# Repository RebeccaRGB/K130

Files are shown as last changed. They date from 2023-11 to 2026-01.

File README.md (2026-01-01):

# K130
Battlestation keyboard with 130 keys! It's an ANSI keyboard! It's an ISO keyboard! It's a JIS keyboard! It's all of the above!

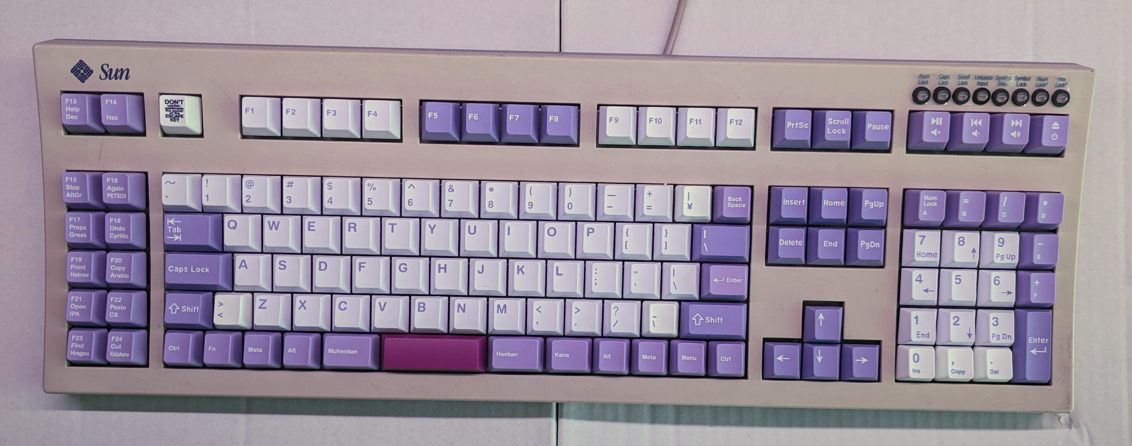
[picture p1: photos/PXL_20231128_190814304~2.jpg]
Thing 1


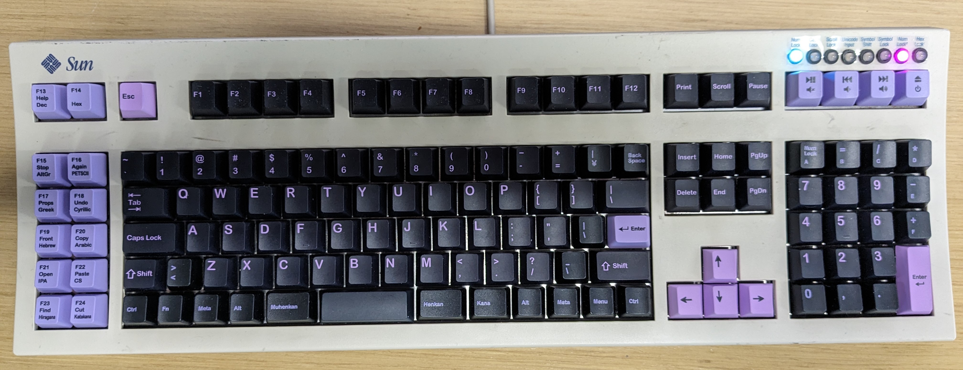
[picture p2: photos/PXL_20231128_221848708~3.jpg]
Thing 2


I have successfully built and used two of these keyboards, so the design and software is pretty much done, but the documentation is still a work in progress.

## Stuff to Get
* 130x Cherry MX compatible keyswitches
* 130x through-hole 1N4148 diodes
* 1x through-hole 1-pin male header
* 3x through-hole 4-pin 2.54mm-spacing male header
* 3x through-hole 5-pin 2.54mm-spacing male header
* 1x through-hole 11-pin 2.54mm-spacing male header
* 1x through-hole 12-pin 2.54mm-spacing male header
* 2x through-hole 14-pin 2.54mm-spacing male header
* 10x Mill-Max Manufacturing Corp 0906-8-15-20-76-14-11-0 POGO pins (FANCY!)
* 1x Teensy 4.0 microcontroller
* 1x through-hole 6-switch DIP switches
* 3x through-hole 150 ohm resistors
* 3x through-hole LEDs *or* 3x through-hole NeoPixel LEDs *or* 1x NeoPixel strip
* 1x USB-B connector *or* 1x microUSB-B connector
* 2x 2u stabilizers
* a standard set of keycaps
* a case specifically from a Sun Microsystems Type 5c keyboard (these are plentiful on eBay and you don't have to feel bad about gutting one since the membrane on these things is pure crap)

## Stuff to Make
* 1x keyboard matrix PCB, made from the Gerber files in the `K130-matrix-gerber` directory
* 1x keyboard encoder PCB, made from the Gerber files in the `K130-encoder-gerber` directory
* 1x aluminum mounting plate, made from the `K130-plate.svg` file
* a bunch of additional keycaps for the 30 or so other keys, made from the templates in the `keycaps` directory (more details needed)

## Stuff to Do
* Program the Teensy 4.0 microcontroller with the Arduino sketch in the `Arduino/K130` directory
* Solder in the diodes on the matrix PCB **first**
* Insert the stabilizers into the aluminum mounting plate
* Insert the keyswitches into the aluminum mounting plate and matrix PCB
* Double check with a multimeter that all the keyswitches work!
* Only **after** checking the keyswitches solder them to the matrix PCB!
* Assemble the encoder board
* Solder the matrix board to the encoder board **last**
* Install the keycaps
* Check that the keyboard works
* Assemble the keyboard case

## DIP Switches
* SW1 OFF, SW2 OFF - Universal mode. ANSI, ISO, and JIS layout simultaneously.
* SW1 ON, SW2 OFF - ANSI mode. Remaps JIS yen → backspace, ISO backslash → enter, ISO less/greater → left shift, JIS backslash → right shift, JIS muhenkan/henkan/kana → space.
* SW1 OFF, SW2 ON - ISO mode. Remaps JIS yen → backspace, ANSI backslash → enter, JIS backslash → right shift, JIS muhenkan/henkan/kana → space.
* SW1 ON, SW2 ON - JIS mode. Remaps ANSI backslash → enter, ISO less/greater → left shift.
* SW3 OFF - PC modifier layout. Ctrl, Meta, Alt on left side; Alt, Meta, Ctrl on right side.
* SW3 ON - Mac modifier layout. Ctrl, Alt, Meta on left side; Meta, Alt, Ctrl on right side.
* With SW6 OFF:
  * SW4 OFF - Left keypad is mapped to F13-F24.
  * SW4 ON - Left keypad is mapped to corresponding keys on a Sun keyboard (Help, Stop, Props, Front, Open, Find, Again, Undo, Copy, Paste, Cut).
  * SW5 OFF - Numeric keypad is mapped normally.
  * SW5 ON - Num lock, =, /, \*, -, + are mapped to letter keys A-F, giving you a hexadecimal pad.
* With SW6 ON:
  * **Super input mode!**
  * Press Dec for Unicode decimal input. Press Hex for Unicode hexadecimal input.
  * Press Dec twice to toggle **num lock lock**. The numeric keypad will always produce numbers regardless of num lock.
  * Press Hex twice to toggle **hex lock lock**. Like num lock lock, except with a hexadecimal pad.
  * Press other left keypad keys once to input a non-ASCII character.
  * Press twice to input multiple non-ASCII characters.
  * Press twice again to return to normal input.
  * SW4 OFF, SW5 OFF - Unix mode; non-ASCII characters are input using Ctrl+Shift+U + code point in hex.
  * SW4 ON, SW5 OFF - Windows decimal mode; non-ASCII characters are input using Alt + Numpad 0 + code point in decimal.
  * SW4 OFF, SW5 ON - Windows hexadecimal mode; non-ASCII characters are input using Alt + Numpad Plus + code point in hex.
  * SW4 ON, SW5 ON - Mac mode; non-ASCII characters are input using Option + UTF-16 code units in hex.

## Layouts
In **super input mode**, the left keypad keys can be used to switch to the following layouts.

### US AltGr Layout
The F15/AltGr left keypad key enters the characters on the right.
The standard US layout is shown on the left for reference.



### PETSCII Layout
The F16/PETSCII left keypad key enters the characters on the right.
The standard US layout is shown on the left for reference.



### Greek Symbol Layout
The F17/Greek left keypad key enters the characters on the left if the Alt
key is released or the characters on the right if the Alt key is pressed.



### Cyrillic Layout
The F18/Cyrillic left keypad key enters the characters on the left if the Alt
key is released or the characters on the right if the Alt key is pressed.



### Hebrew Layout
The F19/Hebrew left keypad key enters the characters on the left if the Alt
key is released or the characters on the right if the Alt key is pressed.



### Arabic Layout
The F20/Arabic left keypad key enters the characters on the left if the Alt
key is released or the characters on the right if the Alt key is pressed.



### IPA Layout
The F21/IPA left keypad key enters the characters on the left if the Alt
key is released or the characters on the right if the Alt key is pressed.



### Sitelen Pona Layout
The F22/CS left keypad key enters the characters on the left if the Alt
key is released or the characters on the right if the Alt key is pressed.



### JIS Hiragana Layout
The F23/Hiragana left keypad key enters the characters on the right.
The standard JIS layout is shown on the left for reference.



### JIS Katakana Layout
The F24/Katakana left keypad key enters the characters on the right.
The standard JIS layout is shown on the left for reference.



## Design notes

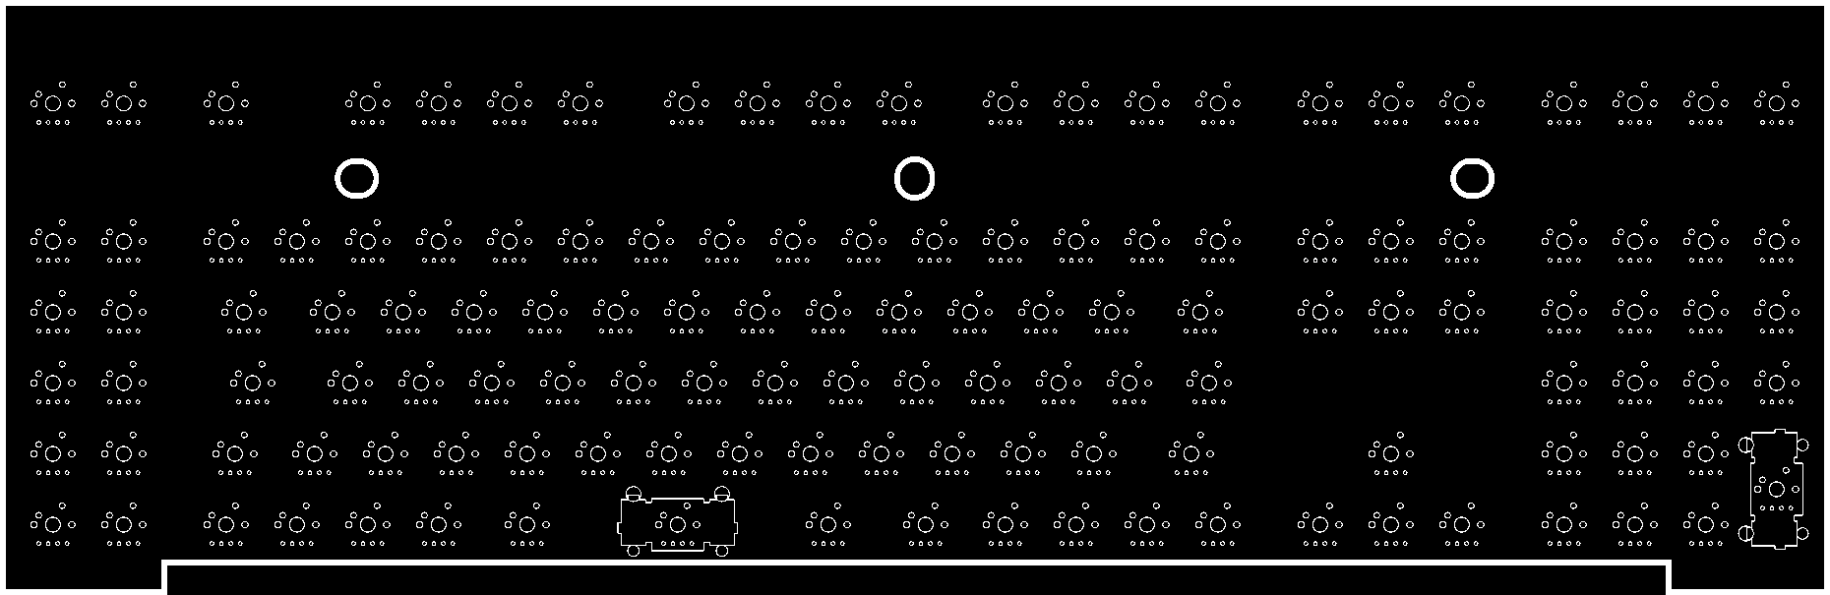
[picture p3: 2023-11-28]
K130-matrix-fritzing/K130.png

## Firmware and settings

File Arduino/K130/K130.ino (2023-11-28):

#include <Adafruit_NeoPixel.h>
#include <Arduino.h>
#include <avr/pgmspace.h>
#include <usb_keyboard.h>
#include <util/delay.h>
#include "layout_arabic.h"
#include "layout_cyrillic.h"
#include "layout_dead_keys.h"
#include "layout_hebrew.h"
#include "layout_ipa.h"
#include "layout_jis.h"
#include "layout_petscii.h"
#include "layout_sitelen_pona.h"
#include "layout_symbol.h"
#include "layout_us.h"
#include "layouts.h"
#include "leds.h"
#include "matrix.h"
#include "remap.h"
#include "super_input.h"
#include "switches.h"
#include "translate.h"
#include "unicode.h"
#include "usbk.h"

void setup() {
  switches_init();
  matrix_init();
  leds_init_rgb_daisy();
}

void loop() {
  unsigned int p = matrix_read_packet();
  if (p) {
    unsigned int q = translate_packet(p);
    if (q) {
      unsigned char r = q;
      unsigned char s = ~switches_read();
      unsigned char m = usbk_output_report()[0];

      switch (s & 3) {
        case 1: r = remap_ansi(r); break;
        case 2: r = remap_iso(r); break;
        case 3: r = remap_jis(r); break;
      }
      if (s & 4) r = remap_mac(r);

      if (s & 32) {
        if (q & MTX_PRESSED) {
          switch (r) {
            case 0x68: super_input_dec(); return;
            case 0x69: super_input_hex(); return;
            case 0x6A: layout_input_start(layout_us_alt, LAYOUT_MODMASK_2LAYER); return;
            case 0x6B: layout_input_start(layout_petscii_alt, LAYOUT_MODMASK_2LAYER); return;
            case 0x6C: layout_input_start(layout_symbol_layered, LAYOUT_MODMASK_4LAYER); return;
            case 0x6D: layout_input_start(layout_cyrillic_layered, LAYOUT_MODMASK_4LAYER); return;
            case 0x6E: layout_input_start(layout_hebrew_qwerty, LAYOUT_MODMASK_4LAYER); return;
            case 0x6F: layout_input_start(layout_arabic_qwerty, LAYOUT_MODMASK_4LAYER); return;
            case 0x70: layout_input_start(layout_ipa_layered, LAYOUT_MODMASK_4LAYER); return;
            case 0x71: layout_input_start(layout_sitelen_pona, LAYOUT_MODMASK_4LAYER); return;
            case 0x72: layout_input_start(layout_jis_hiragana, LAYOUT_MODMASK_2LAYER); return;
            case 0x73: layout_input_start(layout_jis_katakana, LAYOUT_MODMASK_2LAYER); return;
            default: if (super_input(r, s, m)) return;
          }
        }
      } else {
        if (s & 8) r = remap_unix(r);
        if (s & 16) r = remap_hexpad(r);
      }

      if (q & MTX_PRESSED) {
        switch (r) {
          case 0x7F: Keyboard.press((m & USBK_MOD_ANY_ALT) ? KEY_MEDIA_PLAY_PAUSE : KEY_MEDIA_MUTE); break;
          case 0x81: Keyboard.press((m & USBK_MOD_ANY_ALT) ? KEY_MEDIA_PREV_TRACK : KEY_MEDIA_VOLUME_DEC); break;
          case 0x80: Keyboard.press((m & USBK_MOD_ANY_ALT) ? KEY_MEDIA_NEXT_TRACK : KEY_MEDIA_VOLUME_INC); break;
          case 0x66: Keyboard.press((m & USBK_MOD_ANY_ALT) ? KEY_MEDIA_EJECT : KEY_SYSTEM_POWER_DOWN); break;
          default: usbk_key_pressed(r); break;
        }
      }
      if (q & MTX_RELEASED) {
        switch (r) {
          case 0x7F: Keyboard.release(KEY_MEDIA_PLAY_PAUSE); Keyboard.release(KEY_MEDIA_MUTE); break;
          case 0x81: Keyboard.release(KEY_MEDIA_PREV_TRACK); Keyboard.release(KEY_MEDIA_VOLUME_DEC); break;
          case 0x80: Keyboard.release(KEY_MEDIA_NEXT_TRACK); Keyboard.release(KEY_MEDIA_VOLUME_INC); break;
          case 0x66: Keyboard.release(KEY_MEDIA_EJECT); Keyboard.release(KEY_SYSTEM_POWER_DOWN); break;
          default: usbk_key_released(r); break;
        }
      }
    }
  }

  unsigned char r = usbk_read_leds();
  if (unicode_input_status()) r ^= 0x08;
  if (layout_input_status()) r ^= 0x10;
  if (layout_input_status() & 2) r ^= 0x20;
  if (numpad_numlock_status()) r ^= 0x40;
  if (numpad_hexlock_status()) r ^= 0x80;
  if (usbk_get_error_state()) r ^= 0x80;
  leds_write_rgb_daisy(r);
}

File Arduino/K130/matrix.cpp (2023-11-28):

#include <Arduino.h>
#include <util/delay.h>
#include "matrix.h"

void pinModeJ3(unsigned char mode) {
  pinMode(J3_1, mode);
  pinMode(J3_2, mode);
  pinMode(J3_3, mode);
  pinMode(J3_4, mode);
  pinMode(J3_5, mode);
  pinMode(J3_6, mode);
  pinMode(J3_7, mode);
  pinMode(J3_8, mode);
  pinMode(J3_9, mode);
  pinMode(J3_10, mode);
  pinMode(J3_11, mode);
}

void pinModeJ4(unsigned char mode) {
  pinMode(J4_1, mode);
  pinMode(J4_2, mode);
  pinMode(J4_3, mode);
  pinMode(J4_4, mode);
  pinMode(J4_5, mode);
  pinMode(J4_6, mode);
  pinMode(J4_7, mode);
  pinMode(J4_8, mode);
  pinMode(J4_9, mode);
  pinMode(J4_10, mode);
  pinMode(J4_11, mode);
  pinMode(J4_12, mode);
}

unsigned int digitalReadJ3() {
  unsigned int i = 0;
  if (digitalRead(J3_1 )) i |= 0x0001;
  if (digitalRead(J3_2 )) i |= 0x0002;
  if (digitalRead(J3_3 )) i |= 0x0004;
  if (digitalRead(J3_4 )) i |= 0x0008;
  if (digitalRead(J3_5 )) i |= 0x0010;
  if (digitalRead(J3_6 )) i |= 0x0020;
  if (digitalRead(J3_7 )) i |= 0x0040;
  if (digitalRead(J3_8 )) i |= 0x0080;
  if (digitalRead(J3_9 )) i |= 0x0100;
  if (digitalRead(J3_10)) i |= 0x0200;
  if (digitalRead(J3_11)) i |= 0x0400;
  return i;
}

unsigned int digitalReadJ4() {
  unsigned int i = 0;
  if (digitalRead(J4_1 )) i |= 0x0001;
  if (digitalRead(J4_2 )) i |= 0x0002;
  if (digitalRead(J4_3 )) i |= 0x0004;
  if (digitalRead(J4_4 )) i |= 0x0008;
  if (digitalRead(J4_5 )) i |= 0x0010;
  if (digitalRead(J4_6 )) i |= 0x0020;
  if (digitalRead(J4_7 )) i |= 0x0040;
  if (digitalRead(J4_8 )) i |= 0x0080;
  if (digitalRead(J4_9 )) i |= 0x0100;
  if (digitalRead(J4_10)) i |= 0x0200;
  if (digitalRead(J4_11)) i |= 0x0400;
  if (digitalRead(J4_12)) i |= 0x0800;
  return i;
}

void digitalWriteJ3(unsigned int i) {
  digitalWrite(J3_1,  (i & 0x0001) ? HIGH : LOW);
  digitalWrite(J3_2,  (i & 0x0002) ? HIGH : LOW);
  digitalWrite(J3_3,  (i & 0x0004) ? HIGH : LOW);
  digitalWrite(J3_4,  (i & 0x0008) ? HIGH : LOW);
  digitalWrite(J3_5,  (i & 0x0010) ? HIGH : LOW);
  digitalWrite(J3_6,  (i & 0x0020) ? HIGH : LOW);
  digitalWrite(J3_7,  (i & 0x0040) ? HIGH : LOW);
  digitalWrite(J3_8,  (i & 0x0080) ? HIGH : LOW);
  digitalWrite(J3_9,  (i & 0x0100) ? HIGH : LOW);
  digitalWrite(J3_10, (i & 0x0200) ? HIGH : LOW);
  digitalWrite(J3_11, (i & 0x0400) ? HIGH : LOW);
}

void digitalWriteJ4(unsigned int i) {
  digitalWrite(J4_1,  (i & 0x0001) ? HIGH : LOW);
  digitalWrite(J4_2,  (i & 0x0002) ? HIGH : LOW);
  digitalWrite(J4_3,  (i & 0x0004) ? HIGH : LOW);
  digitalWrite(J4_4,  (i & 0x0008) ? HIGH : LOW);
  digitalWrite(J4_5,  (i & 0x0010) ? HIGH : LOW);
  digitalWrite(J4_6,  (i & 0x0020) ? HIGH : LOW);
  digitalWrite(J4_7,  (i & 0x0040) ? HIGH : LOW);
  digitalWrite(J4_8,  (i & 0x0080) ? HIGH : LOW);
  digitalWrite(J4_9,  (i & 0x0100) ? HIGH : LOW);
  digitalWrite(J4_10, (i & 0x0200) ? HIGH : LOW);
  digitalWrite(J4_11, (i & 0x0400) ? HIGH : LOW);
  digitalWrite(J4_12, (i & 0x0800) ? HIGH : LOW);
}

void matrix_init() {
  pinModeJ3(OUTPUT);
  pinModeJ4(INPUT_PULLUP);
}

static void matrix_read_raw(unsigned char * state) {
  unsigned int i, j3m, p, j4m;
  unsigned char mask;

  for (i = 0; i < MTX_STATE_SIZE; i++) state[i] = 0;

  digitalWriteJ3(-1);
  _delay_us(MTX_PROP_DELAY);

  for (i = 0, mask = 1, j3m = 0x0400; j3m; j3m >>= 1) {
    digitalWriteJ3(~j3m);
    _delay_us(MTX_PROP_DELAY);
    p = ~digitalReadJ4();
    for (j4m = 0x0800; j4m; j4m >>= 1) {
      if (p & j4m) state[i] |= mask;
      if ((mask <<= 1)) continue;
      i++; mask = 1;
    }
  }

  digitalWriteJ3(-1);
  _delay_us(MTX_PROP_DELAY);
}

static unsigned char matrix_xor(unsigned char * state1, unsigned char * state2) {
  unsigned char m = 0;
  for (unsigned int i = 0; i < MTX_STATE_SIZE; i++) {
    m |= state1[i] ^ state2[i];
  }
  return m;
}

void matrix_read(unsigned char * state) {
  unsigned char state1[MTX_STATE_SIZE];
  unsigned char state2[MTX_STATE_SIZE];
  matrix_read_raw(state1);
  matrix_read_raw(state2);
  while (matrix_xor(state1, state2)) {
    matrix_read_raw(state1);
    matrix_read_raw(state2);
  }
  for (unsigned int i = 0; i < MTX_STATE_SIZE; i++) {
    state[i] = state1[i];
  }
}

static unsigned char lastState[MTX_STATE_SIZE] = {0,0,0,0,0,0,0,0,0,0,0,0,0,0,0,0,0,0,0,0};
static unsigned int packetBuffer[MTX_BUFFER_SIZE];
static unsigned int packetBufStart = 0;
static unsigned int packetBufEnd = 0;

static void matrix_write_packet(unsigned int packet) {
  packetBuffer[packetBufEnd] = packet;
  packetBufEnd++;
  packetBufEnd &= (MTX_BUFFER_SIZE-1);
  if (packetBufEnd == packetBufStart) {
    // Buffer overflow. Ignore input.
    packetBufEnd--;
    packetBufEnd &= (MTX_BUFFER_SIZE-1);
  }
}

unsigned int matrix_read_packet() {
  unsigned char nextState[MTX_STATE_SIZE];
  unsigned char released[MTX_STATE_SIZE];
  unsigned char pressed[MTX_STATE_SIZE];
  unsigned char changed = 0;
  unsigned int packet;
  unsigned int i;
  unsigned char m;

  matrix_read(nextState);
  for (i = 0; i < MTX_STATE_SIZE; i++) {
    released[i] = lastState[i] &~ nextState[i];
    pressed[i] = nextState[i] &~ lastState[i];
    changed |= released[i] | pressed[i];
    lastState[i] = nextState[i];
  }

  for (packet = 0, i = 0; i < MTX_STATE_SIZE; i++) {
    for (m = 1; m != 0; m <<= 1, packet++) {
      if (released[i] & m) matrix_write_packet(MTX_RELEASED | packet);
      if (pressed[i] & m) matrix_write_packet(MTX_PRESSED | packet);
    }
  }

  if (changed) delay(MTX_DEBOUNCE_TIME);

  if (packetBufStart == packetBufEnd) return 0;
  packet = packetBuffer[packetBufStart];
  packetBufStart++;
  packetBufStart &= (MTX_BUFFER_SIZE-1);
  return packet;
}
